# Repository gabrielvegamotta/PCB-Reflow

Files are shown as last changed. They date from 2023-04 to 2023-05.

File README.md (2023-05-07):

# PCB Reflow
 A PCB that can help you reflow and solder your SMD components! 

This project is my version of [AfterEarthLTD Solder Plate Reflow](https://github.com/AfterEarthLTD/Solder-Reflow-Plate) (which is an awesome project!). 

## V1.0 - Integrated Heating Bed with Arduino

I decided that I would first recreate the concept of the project (with the heating bed integrated) with more afordable component and add some more funcionality, so I used all PTH components and a Arduino Nano for the MCU (cheaper option for prototyping). 

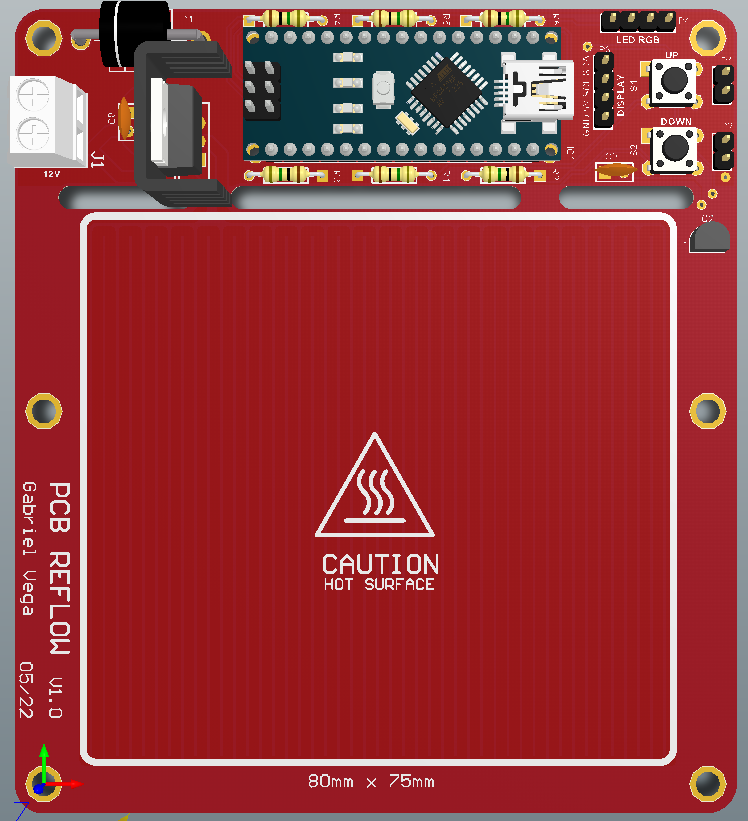
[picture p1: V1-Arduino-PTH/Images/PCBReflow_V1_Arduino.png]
</a>

The board has a bigger heating bed (80mm x75mm) and also implemented a RGB LED socket for easy signaling of the diffent stages of the reflow process.

### Documentation

- [Schematic](V1-Arduino-PTH/Documentation/Schematic_PCB_Reflow_Arduino_V1.0.pdf)
- [Layout](V1-Arduino-PTH/Documentation/Layout_PCB_Reflow_Arduino_V1.0.pdf)
- [3D View](V1-Arduino-PTH/Documentation/PCBReflow_V1_Arduino_Altium.png)
- [BOM](V1-Arduino-PTH/Documentation/BOM_PCB_Reflow_Arduino_V1.0.jpg)

### PCB Assembled

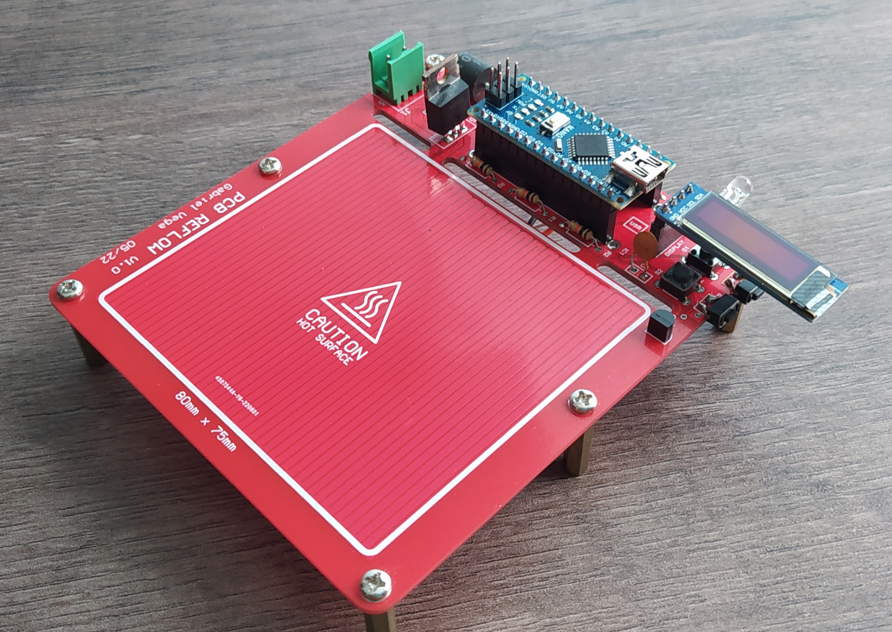
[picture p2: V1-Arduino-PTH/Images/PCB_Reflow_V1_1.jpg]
</a>
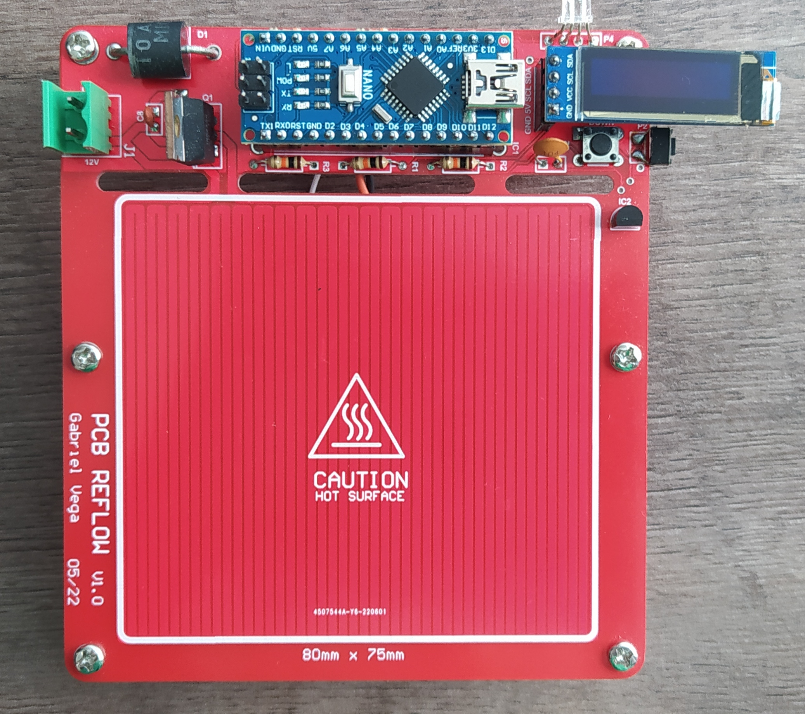
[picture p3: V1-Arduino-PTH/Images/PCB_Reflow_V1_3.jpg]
</a>

### Results & Performance

The board managed to heat at specific set temperatures. But appears to reach only around 190°C max. Any more than that the PCB solder mask will start to decay. If you want higher temperatures, other option for heating element is requiered. 

Also optimizing the firmware and the internal PID to follow the heating curve for the reflow is needed to have a more reliable reflow process.

### Modifications & Upgrades

The first item to be addresed is to change the position of the display connector. My first ideia is to create a 3D printed case to house the display and I would connect with wires. But while I was working on the firmware, the display was over the buttons, blocking them. Not good. So I used some 2 terminal push buttons on the side to help with that.

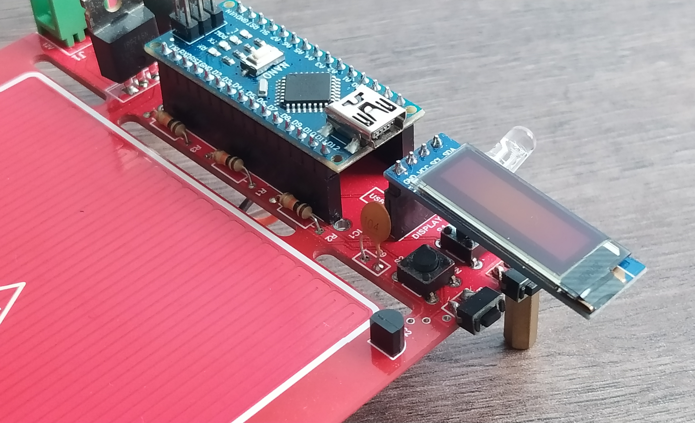
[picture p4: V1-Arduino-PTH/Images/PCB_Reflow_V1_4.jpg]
</a>

The second item is the temperature sensor. While the component itself works fine, the placement is not good. It doesnt give an accurate reading. I tried with an 100k thermistor under the heating bed and got much better results. So for next version I'll use thermistors.

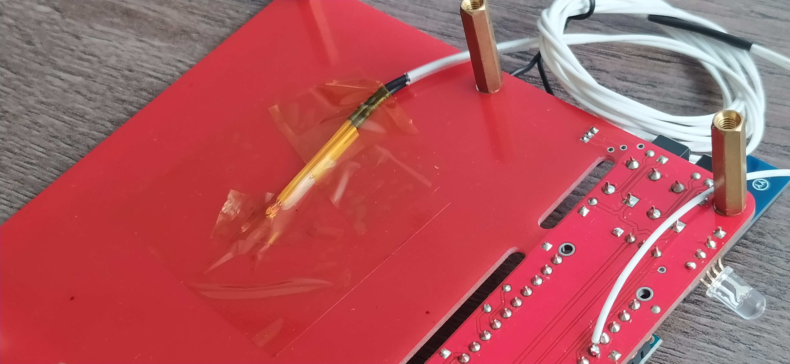
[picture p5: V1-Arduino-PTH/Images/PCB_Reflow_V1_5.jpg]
</a>

### Final Thoughts

A good project to understand more about the hidden aspects of temperature measurement and control. Also a good practice of creating a unusual PCB shape. A new version of this design will be made. This project will work using low temperature solder paste, but if you want to use this as a heating element for higher temperatures, say for desoldering alluminium PCB, other option for heating element is requiered.

### References

 - [AfterEarthLTD Solder Plate Reflow](https://github.com/AfterEarthLTD/Solder-Reflow-Plate)

 - [GreatScott Solder Plate Reflow Review](https://www.youtube.com/watch?v=QarizoUnRfk&t)

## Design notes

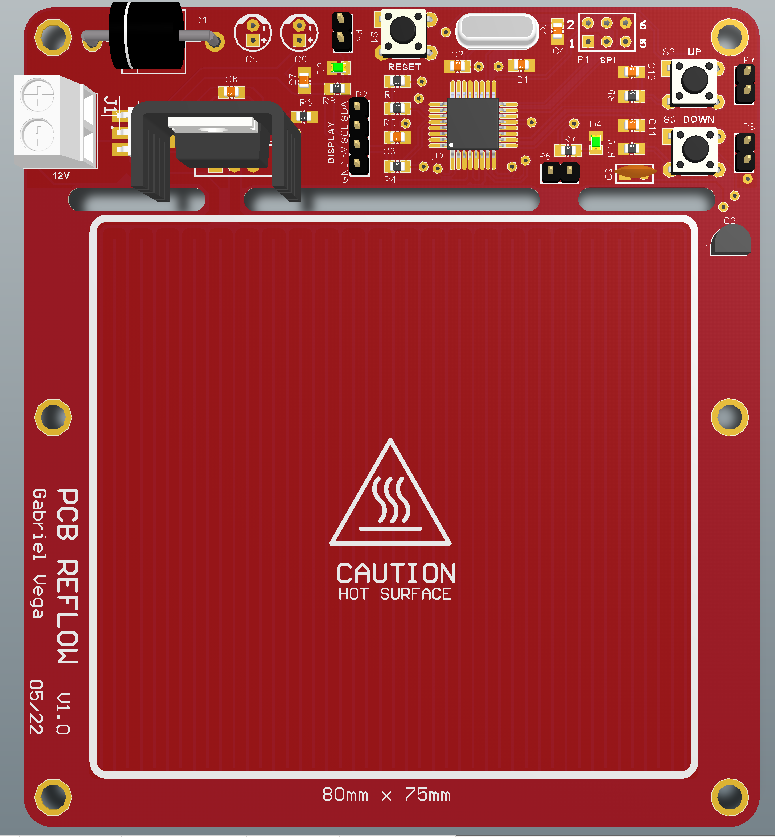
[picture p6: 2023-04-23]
V1-Arduino-PTH/Images/PCBReflow_V1_SMD.png

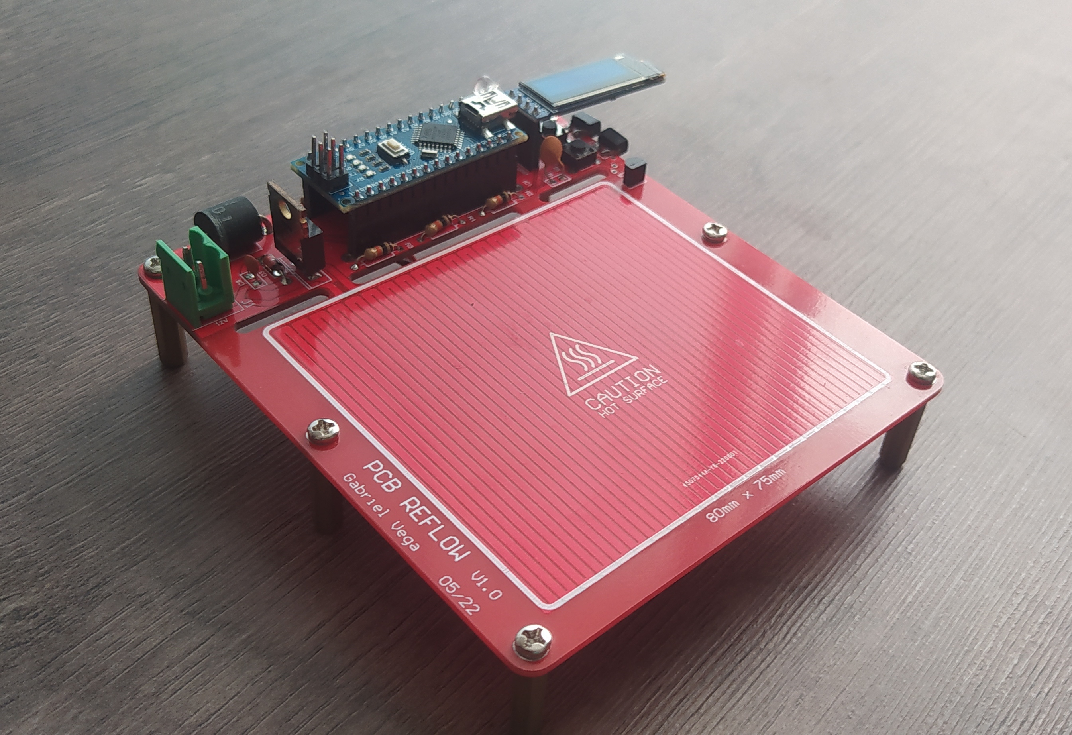
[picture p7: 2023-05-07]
V1-Arduino-PTH/Images/PCB_Reflow_V1_2.jpg

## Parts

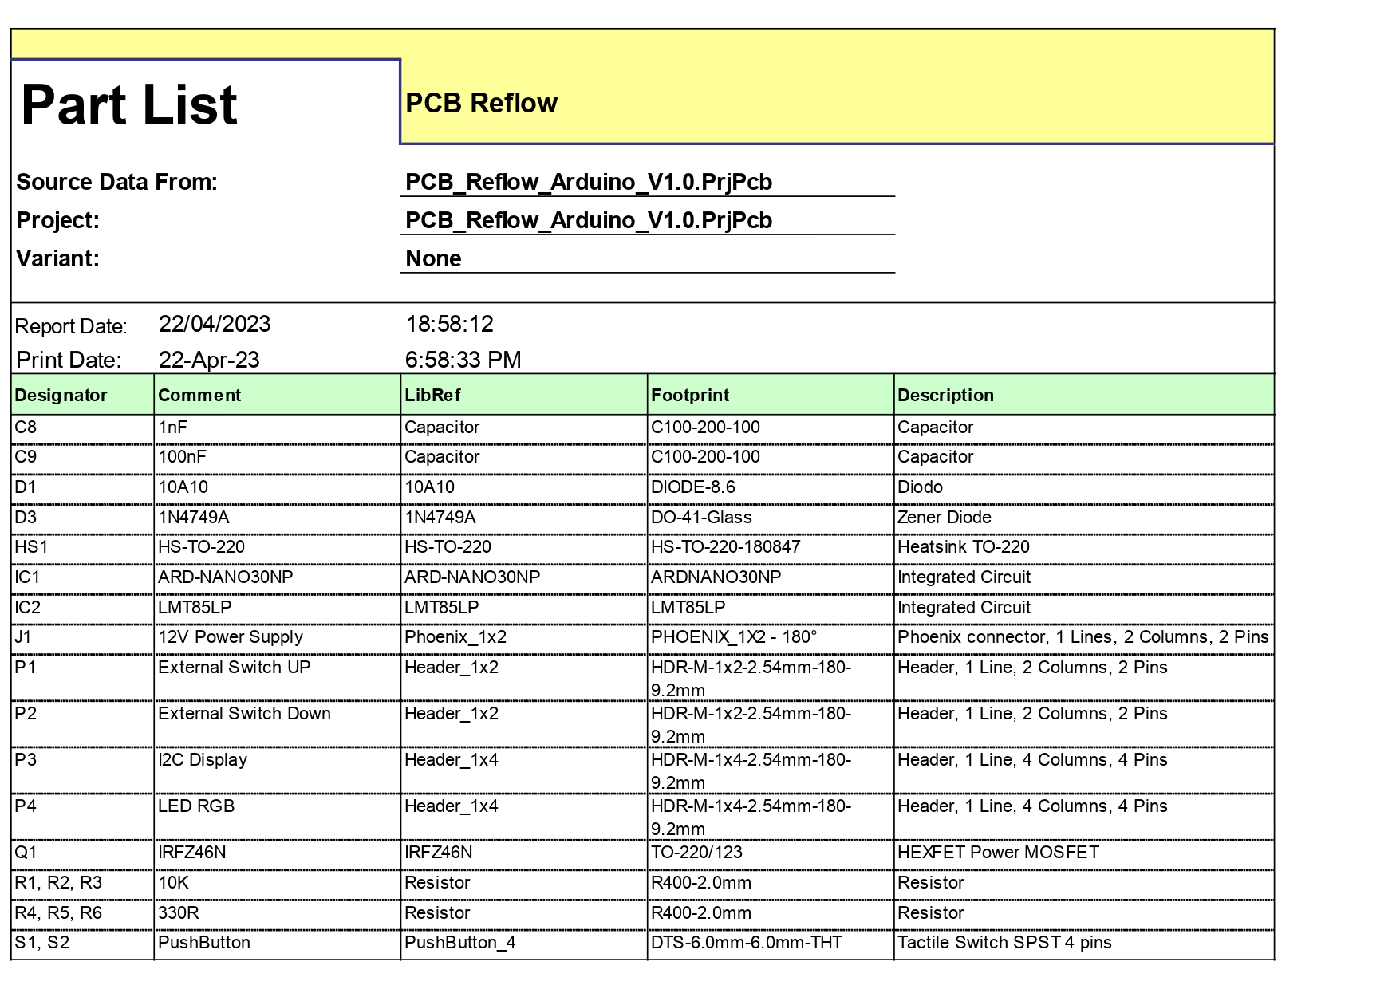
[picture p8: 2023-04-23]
V1-Arduino-PTH/Documentation/BOM_PCB_Reflow_Arduino_V1.0.jpg

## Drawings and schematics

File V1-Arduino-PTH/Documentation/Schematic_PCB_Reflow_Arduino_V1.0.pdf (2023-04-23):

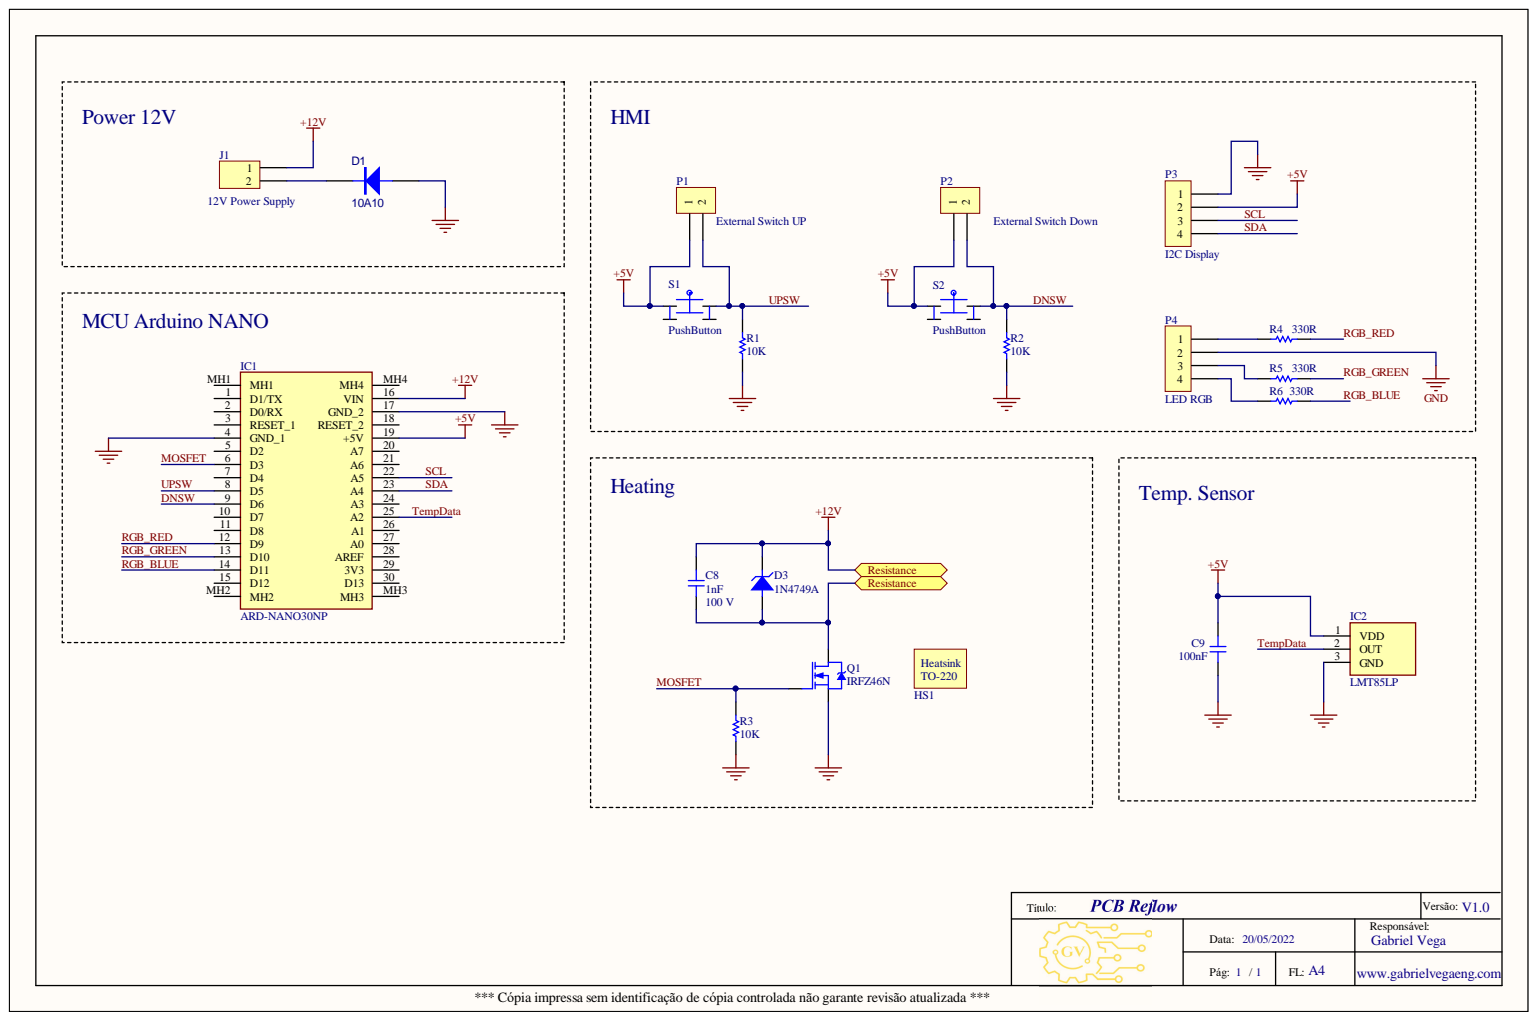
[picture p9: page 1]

T í tu lo : P CB R | Vers ão:

Da t a : | R e s p ons á ve l : Gabriel Ve g a

P á g : 1 / 1 | F L : A4 | www.gabrielveg aen g.com

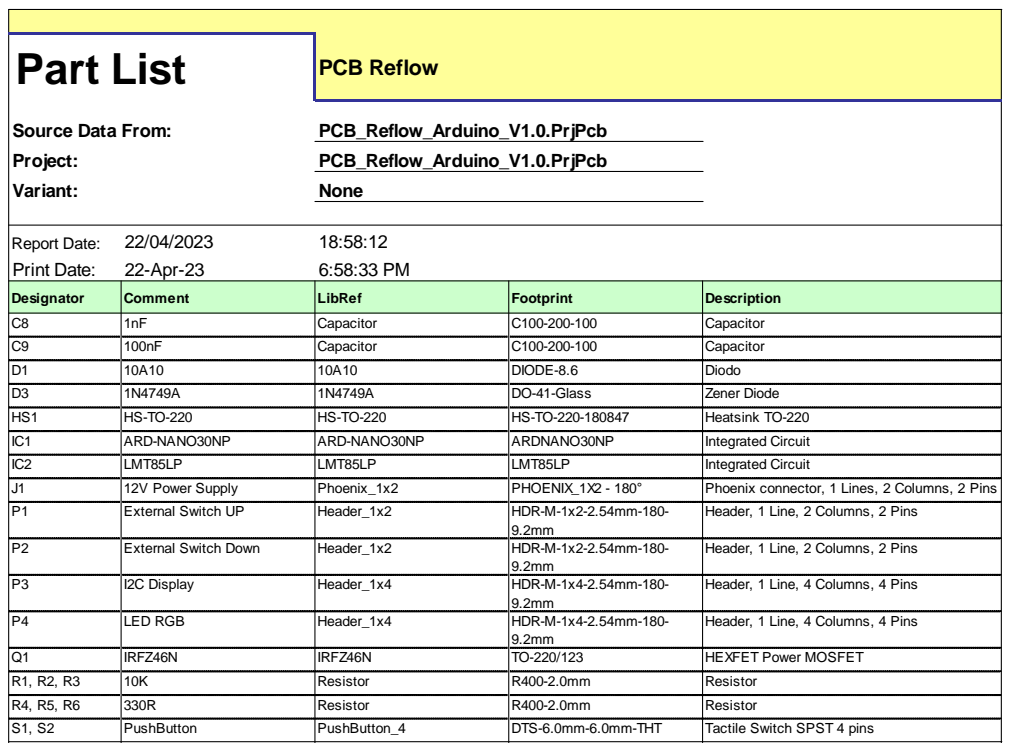
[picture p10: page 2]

Header, 1 Line, 2 Columns, 2 Pins

Header, 1 Line, 4 Columns, 4 Pins

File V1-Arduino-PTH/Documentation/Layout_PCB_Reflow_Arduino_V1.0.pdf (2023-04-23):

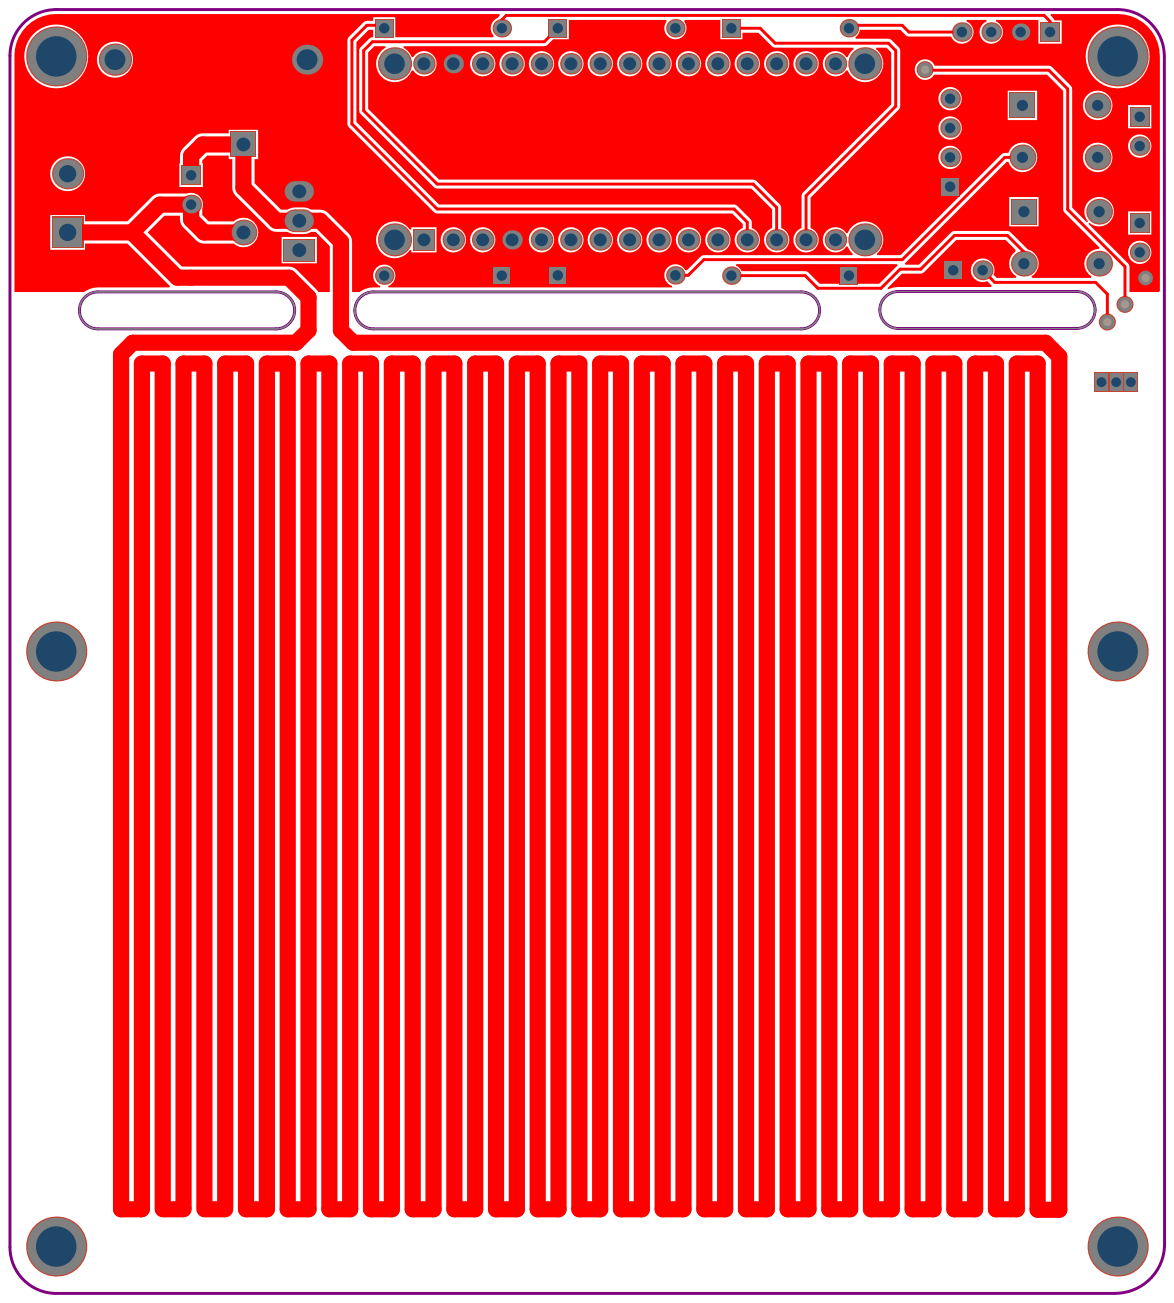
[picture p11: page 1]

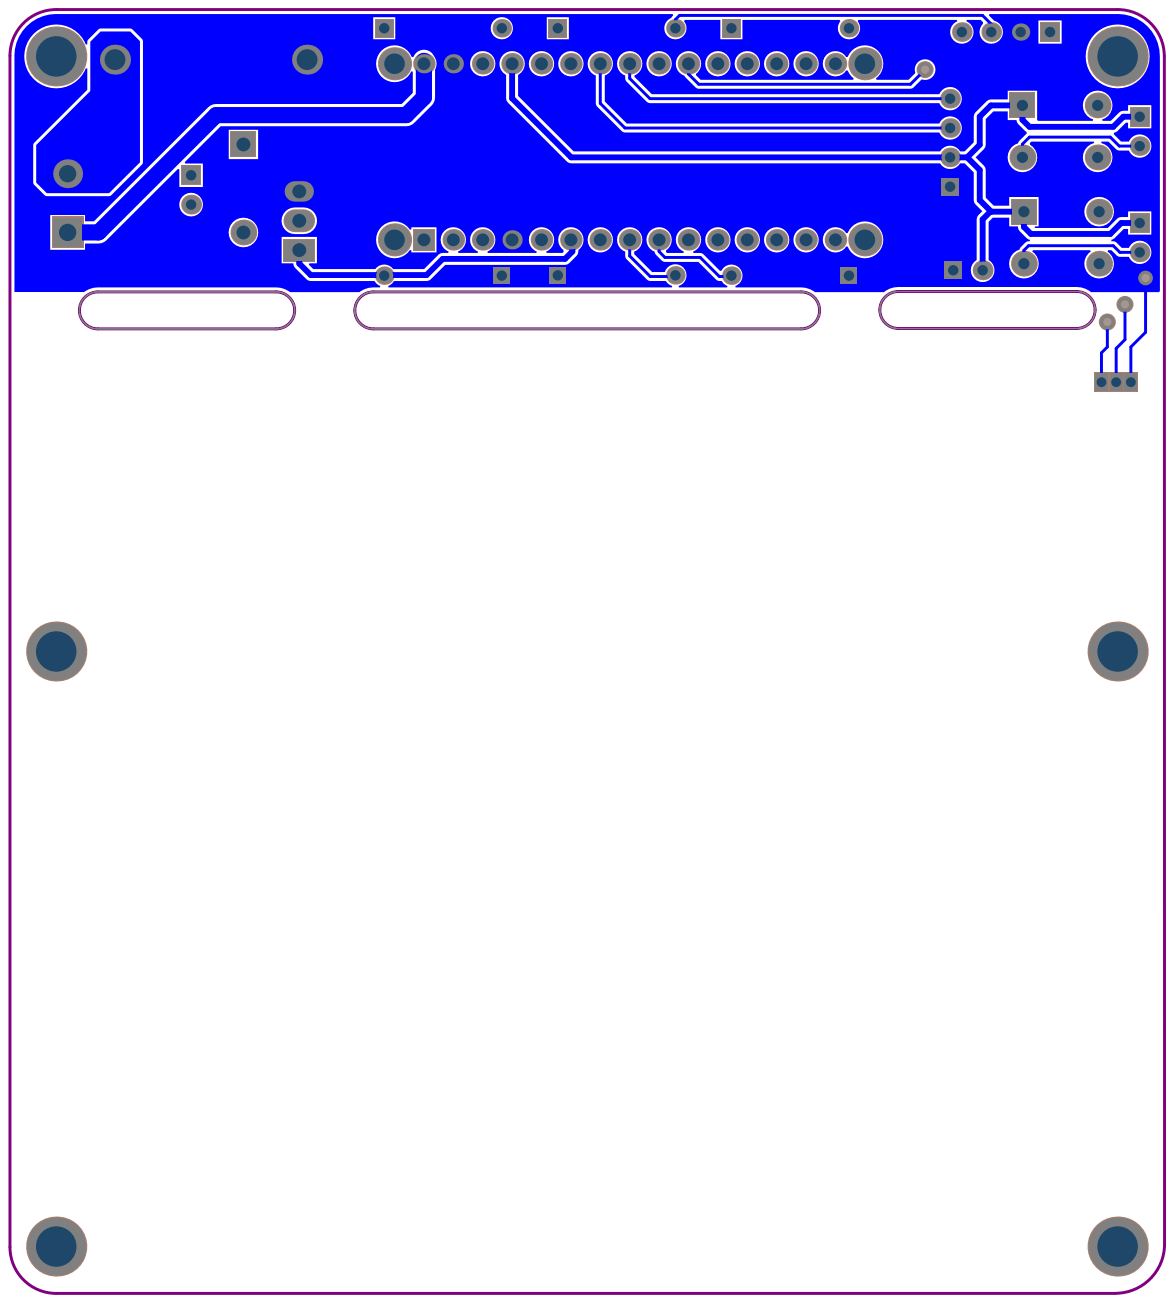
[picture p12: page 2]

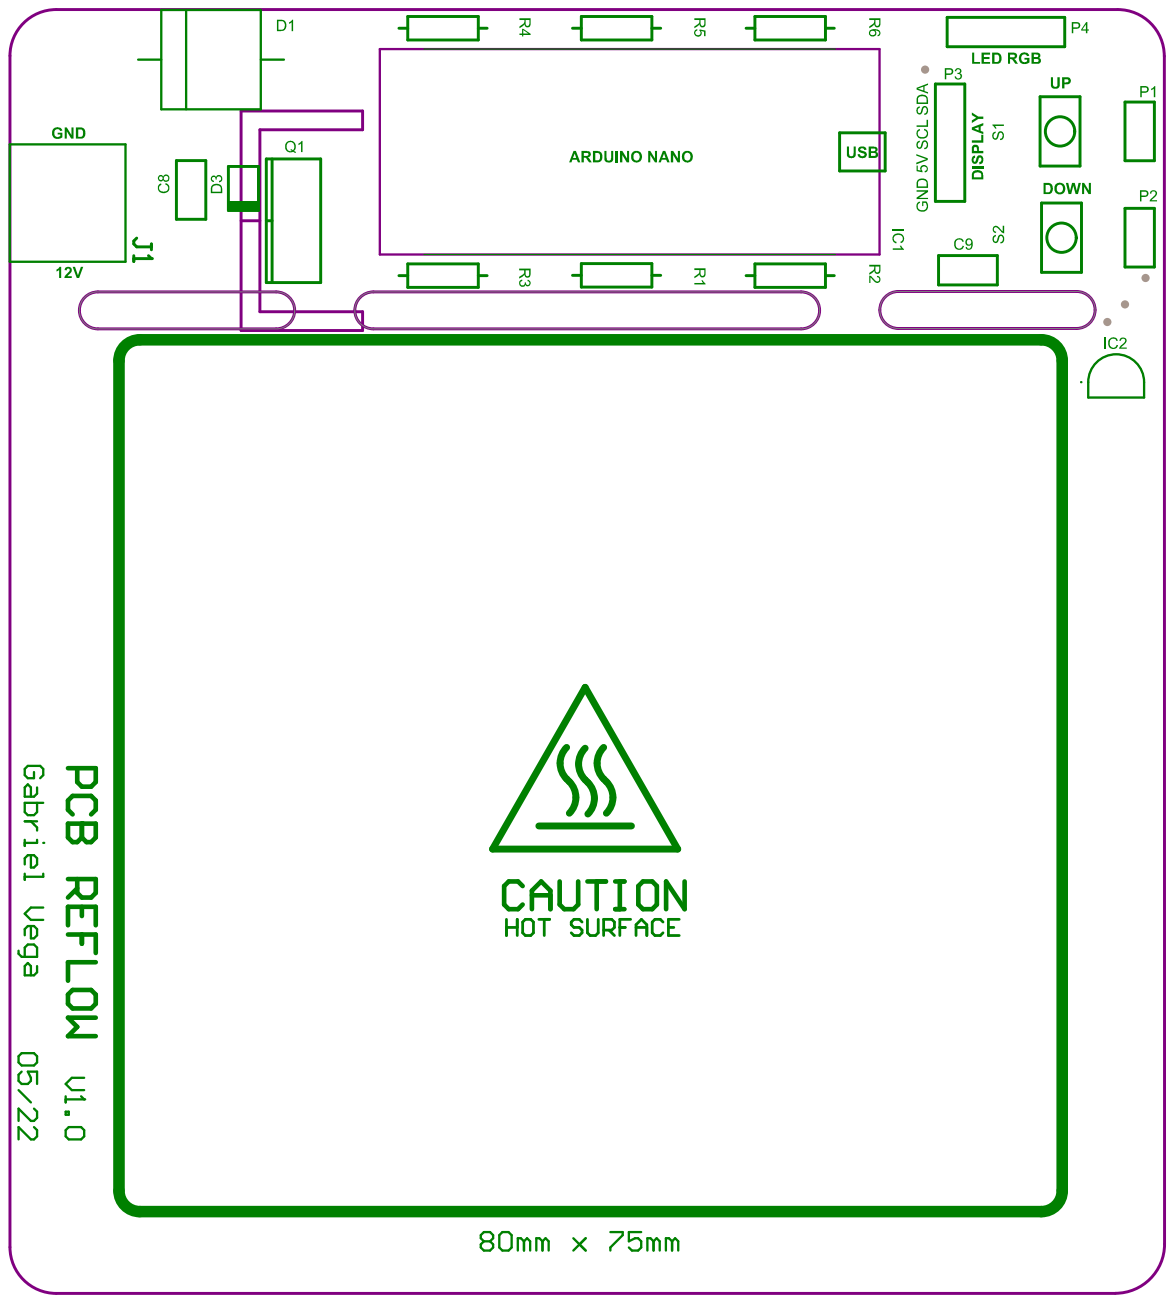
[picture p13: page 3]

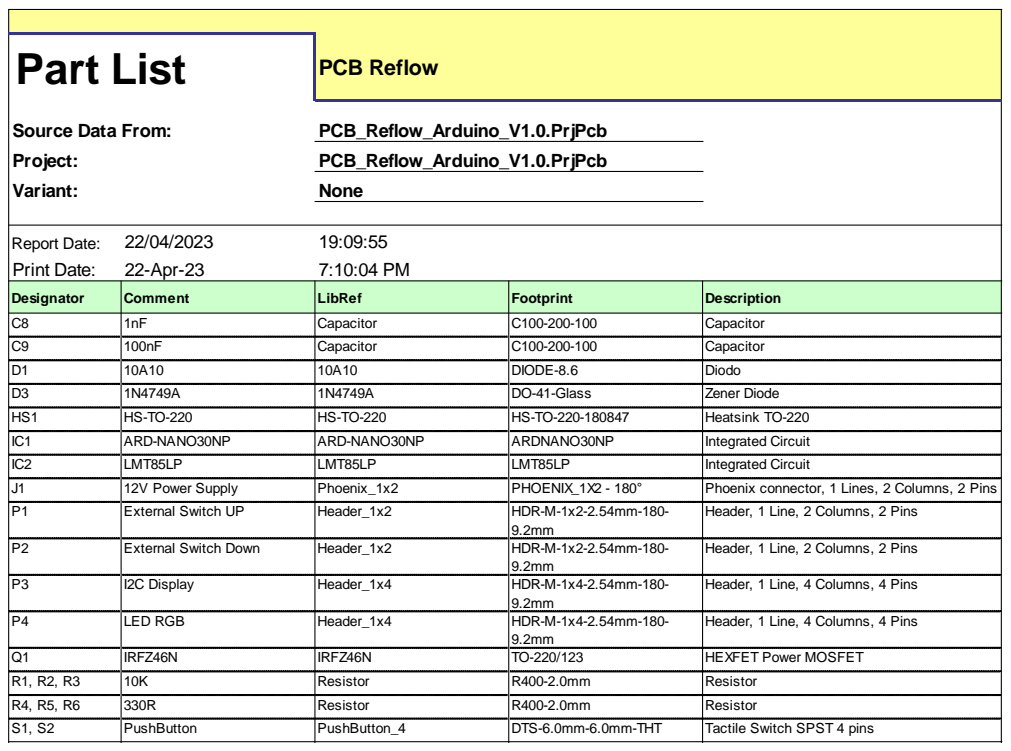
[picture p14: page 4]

Header, 1 Line, 2 Columns, 2 Pins

Header, 1 Line, 4 Columns, 4 Pins

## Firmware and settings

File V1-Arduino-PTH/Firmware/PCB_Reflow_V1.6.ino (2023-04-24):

/* PCB Reflow 
 * Hardware - V1.0
 * Firmware - V1.6
 * 
 * By Gabriel Vega
 *  
 * 11/03/2023 
 * 
 * Inspired by:
 * Solder Reflow Plate Sketch  by Chris Halsall    
 */


#include <SPI.h>
#include <Adafruit_GFX.h>
#include <Adafruit_SSD1306.h>
#include <EEPROM.h>
#include <thermistor.h>

//Version Definitions
static const PROGMEM float hw = 1.0;
static const PROGMEM float sw = 1.6;

//Heating Animation
static const uint8_t PROGMEM heat_animate[] = {
  0b00000001, 0b00000000,
  0b00000001, 0b10000000,
  0b00000001, 0b10000000,
  0b00000001, 0b01000000,
  0b00000010, 0b01000000,
  0b00100010, 0b01000100,
  0b00100100, 0b00100100,
  0b01010101, 0b00100110,
  0b01001001, 0b10010110,
  0b10000010, 0b10001001,
  0b10100100, 0b01000001,
  0b10011000, 0b01010010,
  0b01000100, 0b01100010,
  0b00100011, 0b10000100,
  0b00011000, 0b00011000,
  0b00000111, 0b11100000
};
static const uint8_t heat_animate_width = 16;
static const uint8_t heat_animate_height = 16;

//Screen Definitions
#define SCREEN_WIDTH 128
#define SCREEN_HEIGHT 32
#define SCREEN_ADDRESS 0x3C   //I2C Address
Adafruit_SSD1306 display(SCREEN_WIDTH, SCREEN_HEIGHT, &Wire, -1); //Create Display

//Pin Definitions
#define mosfet PD3
#define upsw PD5
#define dnsw PD6
#define temp PC2            //A2
#define temp_termistor PC1  //A1
#define vcc PC0             //A0

thermistor therm1(A1,0);

#define ledRed  9
#define ledGreen 10  
#define ledBlue 11

//Variables Definitions
float temperatura_thermistor = 0;
float maxTemp = 200;
float targetTemp = 180;
float safeTemp = 50;
int maxTime = 480;          //8 minutos
int x = 0;  //Display change counter
int y = 200; //Display change max (modulused below)

void setup() {
  
  //Pin Direction control
  pinMode(mosfet,OUTPUT);
  digitalWrite(mosfet,LOW);
  pinMode(upsw,INPUT);
  pinMode(dnsw,INPUT);
  pinMode(temp,INPUT);
  pinMode(temp_termistor,INPUT);
  pinMode(vcc,INPUT);

  pinMode(ledRed, OUTPUT);
  pinMode(ledGreen, OUTPUT);
  pinMode(ledBlue, OUTPUT);

  //Start-up Diplay
  display.begin(SSD1306_SWITCHCAPVCC, SCREEN_ADDRESS);
  display.clearDisplay();
  display.setTextSize(2);
  display.setTextColor(SSD1306_WHITE);
  display.setCursor(0,0);
  display.print(F("PCB Reflow"));
  display.setTextSize(1);
  display.setCursor(0,16);
  display.print(F("By:"));
  display.setCursor(0,24);
  display.print(F("Gabriel Vega"));
  display.setCursor(80,16);
  display.print(F("S/W V"));
  display.print(sw, 1);
  display.setCursor(80,24);
  display.print(F("H/W V"));
  display.print(hw, 1);
  display.display();
  delay(3000);
  display.clearDisplay();

}

void loop() {

  temperatura_thermistor = getTemp();

  display.clearDisplay();
  display.setTextSize(1);
  display.setCursor(28,0); 
  display.print(F("Temp: "));
  display.print(temperatura_thermistor);
  display.print(F(" C"));

  display.setCursor(23,10);
  display.print(F("Target: "));
  display.print(targetTemp,1);
  display.print(F(" C"));

  display.setCursor(45,20); 
  display.print(F("Heat OFF"));
  
  if(digitalRead(upsw) == HIGH){
    heatingON();

  }else if(digitalRead(dnsw) == HIGH) {
    digitalWrite(mosfet, LOW);

    display.setTextSize(1);
    display.setCursor(45,20); 
    display.print(F("Heat OFF"));
    display.display();
  }
  display.display();

  if(temperatura_thermistor >= safeTemp){
    ledYELLOW_ON();
  }else {
    ledGREEN_ON();
  }
}

void heatingON(){
  
  unsigned long startTime = 0;
  unsigned long elapsedTime = 0; 

  temperatura_thermistor = getTemp();
  
  startTime = (millis() / 1000);  
  while(temperatura_thermistor <= maxTemp && digitalRead(dnsw) == LOW && elapsedTime <= maxTime){

    temperatura_thermistor = getTemp();

    if(temperatura_thermistor >= targetTemp && elapsedTime <= maxTime){

      display.clearDisplay();
      display.setCursor(30,0); 
      display.print(F("Temp"));
      display.print(temperatura_thermistor);
      display.print(F(" C"));
      
      display.setCursor(42,10);
      display.print(F("Time:")); 
      display.print(elapsedTime);
      display.print(F(" s"));

      display.setCursor(45,20); 
      display.print(F("Heat OFF"));

      display.display();

      digitalWrite(mosfet, LOW);
    }else if(temperatura_thermistor <= targetTemp && elapsedTime <= maxTime){

      display.clearDisplay();
      display.setCursor(30,0); 
      display.print(F("Temp:"));
      display.print(temperatura_thermistor);
      display.print(F(" C"));

      display.setCursor(42,10);
      display.print(F("Time:"));
      display.print(elapsedTime);
      display.print(F(" s"));

      display.setCursor(45,20); 
      display.print(F("Heat ON"));
      
      //Heat Animate Control
      display.drawBitmap( 0, 10, heat_animate, heat_animate_width, heat_animate_height, SSD1306_WHITE);
      display.drawBitmap( 112, 10, heat_animate, heat_animate_width, heat_animate_height, SSD1306_WHITE);
      display.fillRect( 0, 10, heat_animate_width, heat_animate_height * (y - x) / y, SSD1306_BLACK);
      display.fillRect( 112, 10, heat_animate_width, heat_animate_height * (y - x) / y, SSD1306_BLACK);
      x = ( x + 25 ) % y;

      display.display();

      if(temperatura_thermistor < 100){
        digitalWrite(mosfet, HIGH);     
        delay(200);
        digitalWrite(mosfet, LOW);     
        delay(100);

      }else if(temperatura_thermistor > 100){
        digitalWrite(mosfet, HIGH);     
        delay(350);
        digitalWrite(mosfet, LOW);     
        delay(20);
      }
    }

    ledRED_ON();
    elapsedTime = (millis() / 1000) - startTime;
  }

}

float getTemp(){
  float t = 0;
  for (byte i = 0; i < 10; i++){ //Poll temp reading 10 times
    t = t + therm1.analog2temp();
  }
  return ((t / 10) ); //Average, convert to C, and return
}


void ledRED_ON(){
  int r = 255,g = 0,b = 0;
  digitalWrite(ledRed, HIGH);
  digitalWrite(ledGreen, LOW);
  digitalWrite(ledBlue, LOW);
  
}

void ledGREEN_ON(){
  int r = 0,g = 255,b = 0;
  digitalWrite(ledRed, LOW);
  digitalWrite(ledGreen, HIGH);
  digitalWrite(ledBlue, LOW);
}

void ledBLUE_ON(){
  int r = 0,g = 0,b = 255;
  digitalWrite(ledRed, LOW);
  digitalWrite(ledGreen, LOW);
  digitalWrite(ledBlue, LOW);
}

void ledYELLOW_ON(){
  int r = 255,g = 255,b = 0;
  digitalWrite(ledRed, HIGH);
  digitalWrite(ledGreen, HIGH);
  digitalWrite(ledBlue, LOW);
}

void led_OFF(){
  int r = 0,g = 0,b = 0;
  digitalWrite(ledRed, LOW);
  digitalWrite(ledGreen, LOW);
  digitalWrite(ledBlue, LOW);
}
